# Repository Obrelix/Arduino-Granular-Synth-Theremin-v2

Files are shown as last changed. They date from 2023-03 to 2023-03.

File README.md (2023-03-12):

# Arduino-Granular-Synth-Theremin-v2
An Arduino based projects that utilizes an Arduino Mega 2560 board, 5 10k ohms potentiometers, and 2 IR proximity sensors as inputs.
Based on Peter Knight's Arduino Granular Synth project.

You can explore a vast range of sound textures and manipulate them in real-time. This project is ideal for anyone interested in exploring the boundaries of sound synthesis, especially musicians, sound designers, and electronic hobbyists. With its intuitive interface and customizable controls, its provides an accessible way to experiment with sound and create unique compositions. Whether you're a seasoned pro or a curious beginner, this granular synthesizer is a great way to push the boundaries of sound synthesis and explore the infinite possibilities of sound.

## Implementing a granular synthesis algorithm on an embedded system with a PWM (pulse width modulation) output for audio.

Granular synthesis involves dividing an audio sample into small, overlapping pieces called grains, and then manipulating those grains in various ways (such as changing their pitch, duration, or amplitude) to create new sounds. 

In this project, each grain oscillator generates a triangular waveform with an exponential decay envelope, and the two oscillators are summed together to create the final output sample.

The phase accumulator is a variable that keeps track of the current phase of the oscillator, and is incremented on each audio sample interval. 

The sync phase increment is the amount by which the phase accumulator is incremented each sample interval, and determines the frequency of the oscillator.

The lookup table is used to convert the phase of the oscillator into a triangular waveform. 

The triangle wave is used to modulate the amplitude of the oscillator, which creates the characteristic shape of the exponential decay envelope.

The clipping step ensures that the output sample remains within the range of values that can be represented by the PWM output. Clipping can introduce distortion into the sound, but is often used in audio processing to prevent overdriving the output.

## Bill of Materials
[Arduino Mega 2560 R3](https://www.aliexpress.com/item/1005001621770748.html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) x 1

[IR Proximity Sensor (GP2Y0A41SK0f)](https://www.aliexpress.com/item/1005003745155535.html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) x 2

[Linear Potentiometer 10Κ Ω](https://www.aliexpress.com/item/1005003390403815.html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) x 5

[Toggle Switch (On-Off-On)](https://www.aliexpress.com/item/1005002378931076.html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) x 1

[Momentary Push Button](https://www.aliexpress.com/item/4000164264475.html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) x 1

[LED 5mm](https://www.aliexpress.com/item/32731407139.html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) x 3

[Round Rocker Switch 3Pin red light](https://www.aliexpress.com/item/4000896270246.html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) x 1

[DC Power Jack 5.5 x 2.1 mm](https://www.aliexpress.com/item/33024078085.html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) x 1

[2 Pole Mono 3.5mm audio jack](https://www.aliexpress.com/item/4000169463441.html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) x 1
## Video	
 Watch the video (https://youtu.be/2OcyxWDMjQo)
## Images	
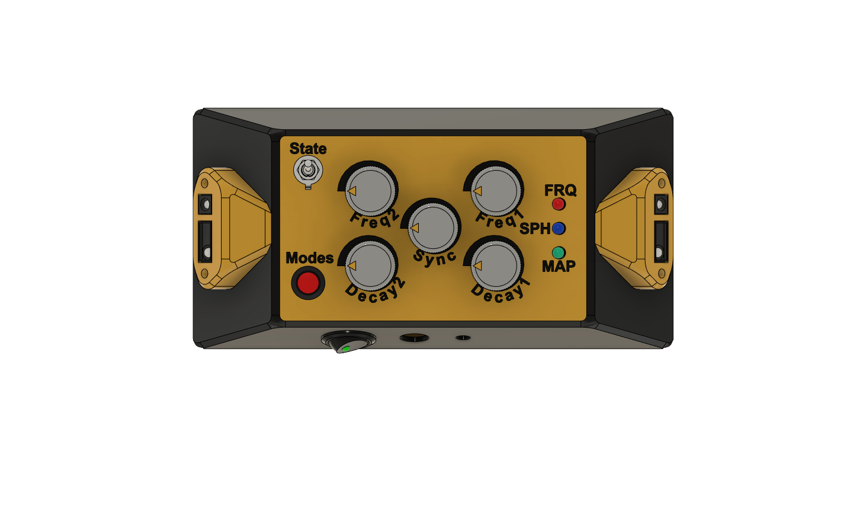
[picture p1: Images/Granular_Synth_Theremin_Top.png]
 
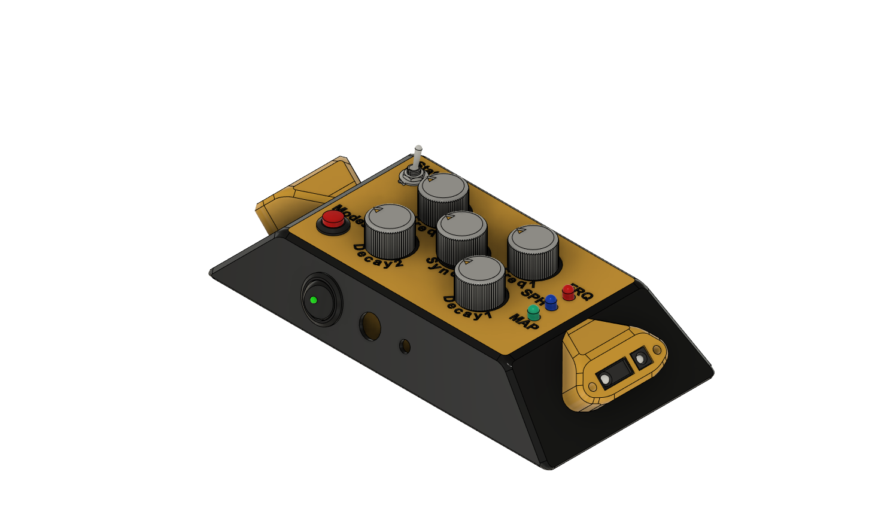
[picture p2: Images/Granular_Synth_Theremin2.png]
 
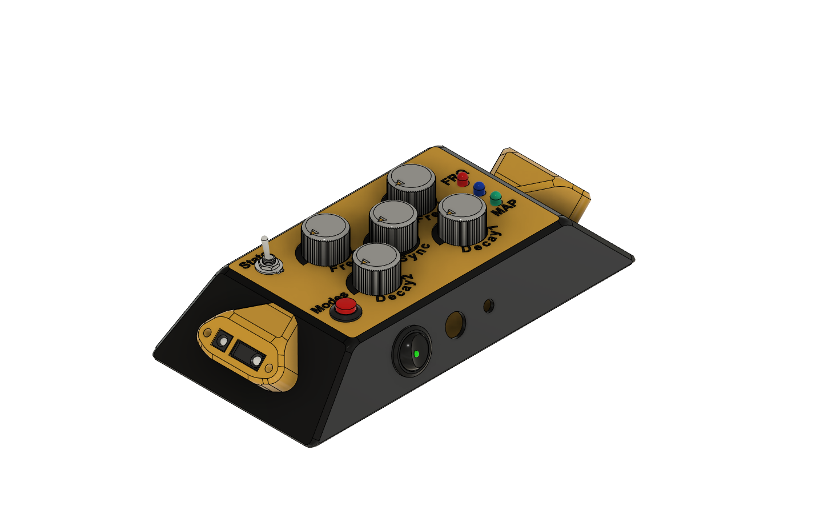
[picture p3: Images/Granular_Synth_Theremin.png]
 
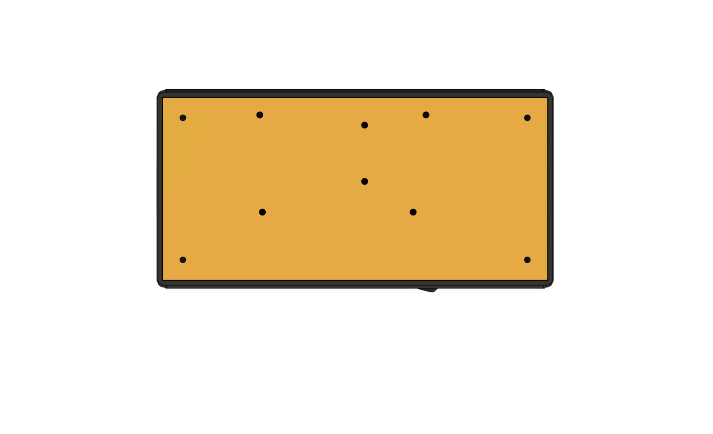
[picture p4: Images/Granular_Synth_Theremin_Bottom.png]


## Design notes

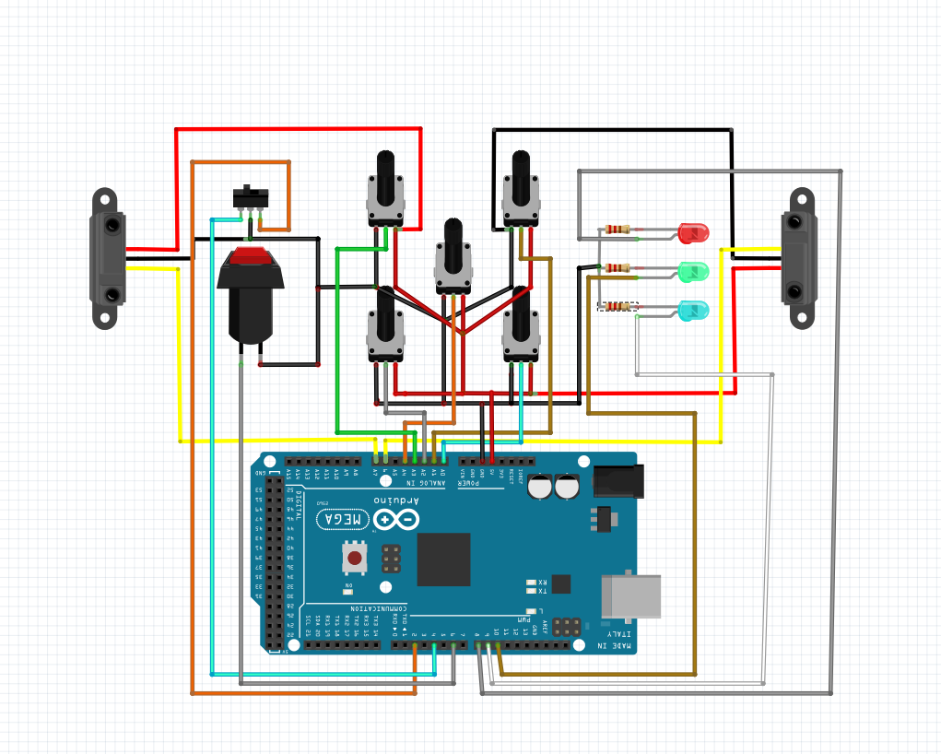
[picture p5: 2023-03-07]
Images/FritzingSchema.PNG

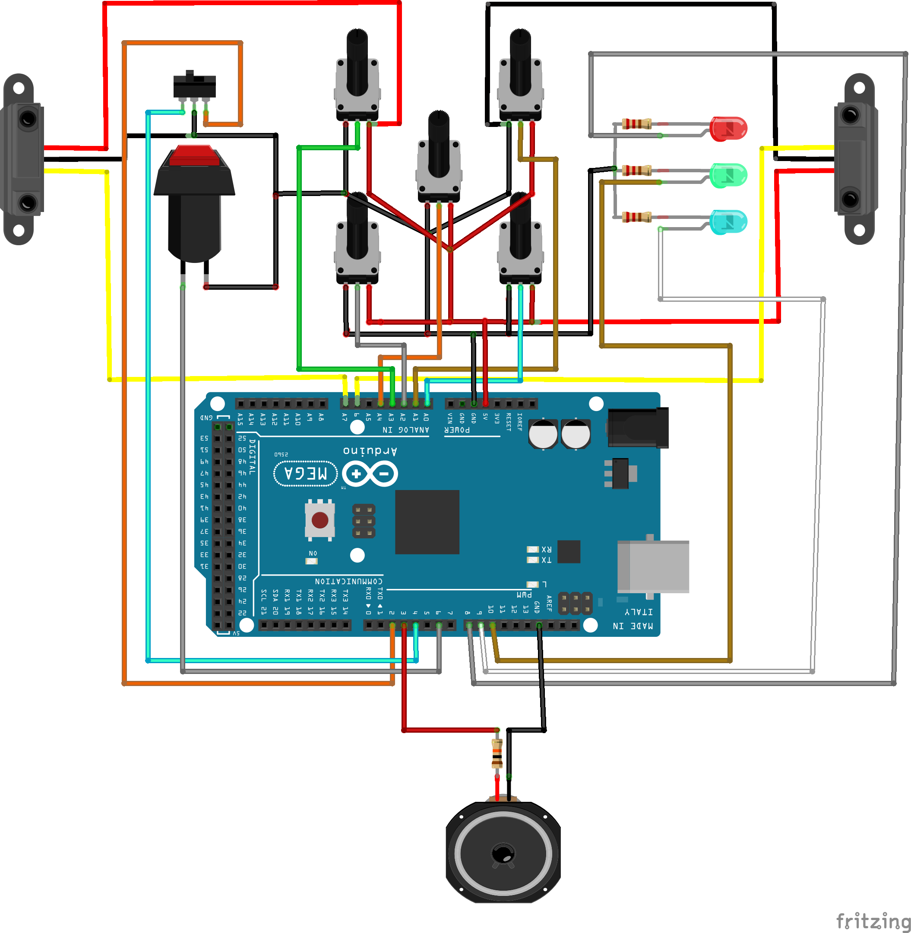
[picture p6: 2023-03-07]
Images/Arduino_Granular_Synth_Theremin_bb.png

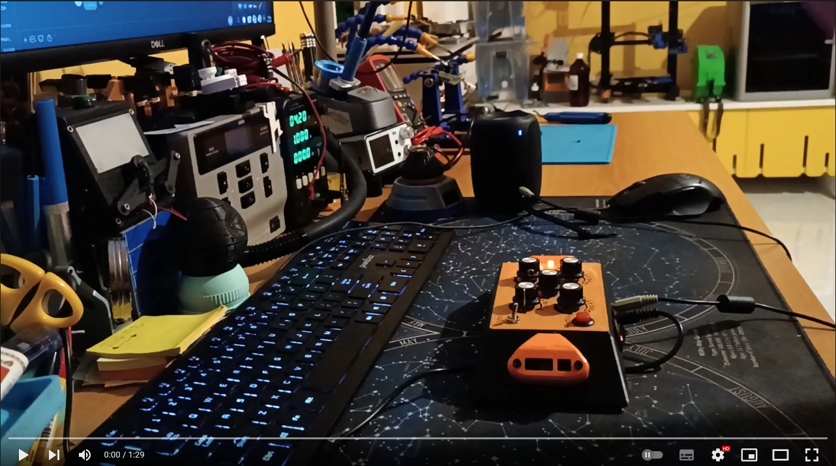
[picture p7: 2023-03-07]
Images/Video Capture.PNG

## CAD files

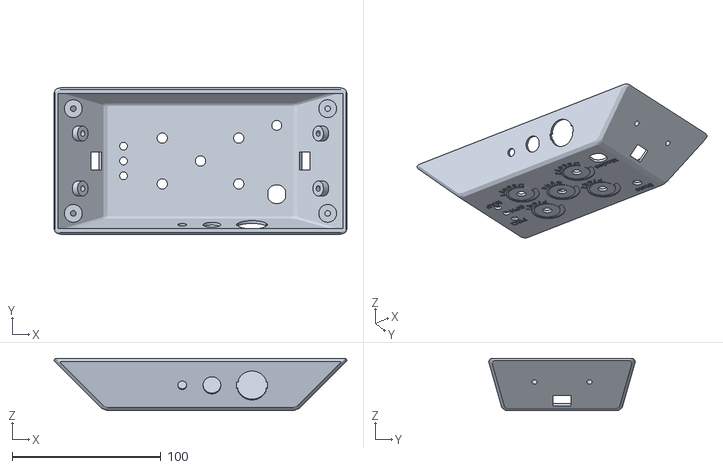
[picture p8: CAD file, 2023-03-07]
STL Files/Main Box.stl
197.2 x 98.9 x 35.0

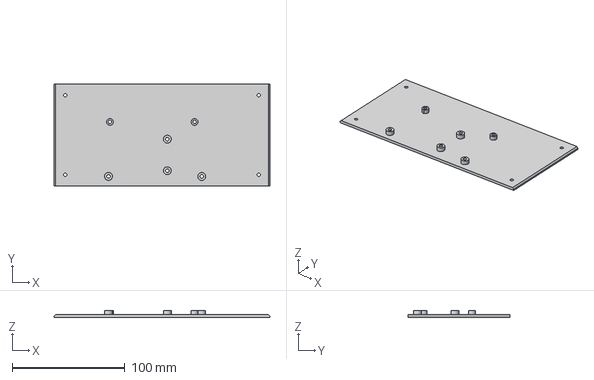
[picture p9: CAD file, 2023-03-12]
Step Files/Bottom-Lid.step
191.2 x 90.5 x 6.25 mm

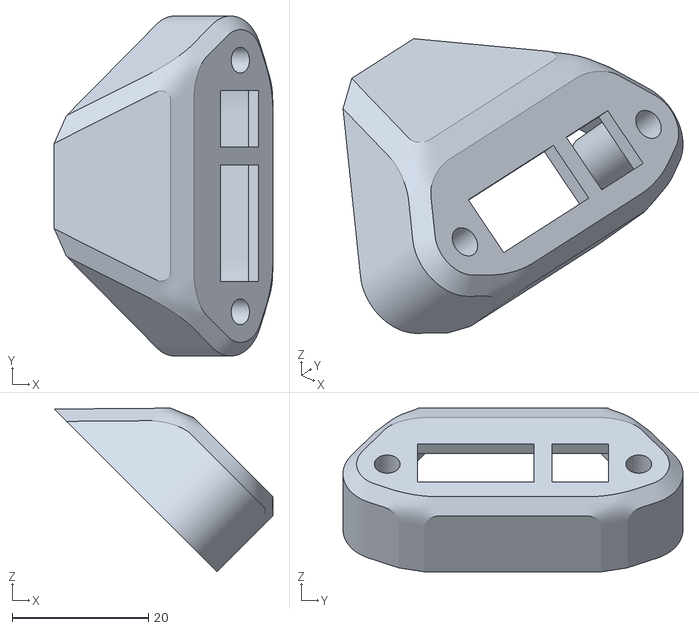
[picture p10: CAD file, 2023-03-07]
STL Files/Distance Sensor Cap.stl
32.2 x 50.0 x 24.1

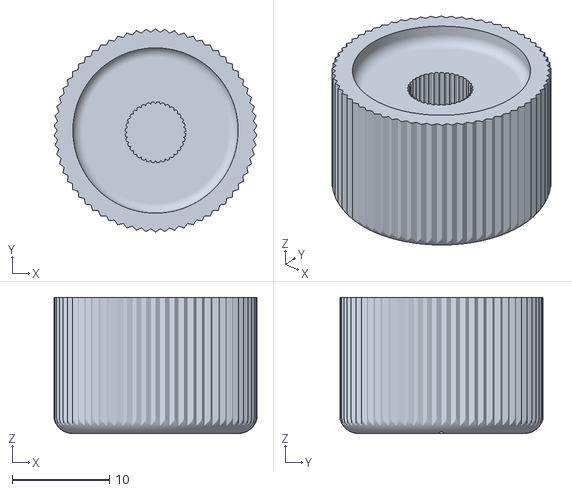
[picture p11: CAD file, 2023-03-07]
STL Files/Knob.stl
20.9 x 20.9 x 14.0

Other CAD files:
Step Files/Proximity-Sensor-Cap.step
STL Files/Bottom-Lid.stl

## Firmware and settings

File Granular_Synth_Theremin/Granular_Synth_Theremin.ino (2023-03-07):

// Based on Peter Knight's Arduino Granular Synth project 
// https://github.com/ndonegan/auduino/blob/master/auduino.pde
#include <avr/io.h>
#include <avr/interrupt.h>
// Define Analogue Inputs
#define SYNC_CONTROL         (4) // Sync pot pin
#define GRAIN_FREQ_CONTROL   (1) // Freq1 pot pin
#define GRAIN_DECAY_CONTROL  (0) // Decay1 pot pin
#define GRAIN2_FREQ_CONTROL  (3) // Freq2 pot pin
#define GRAIN2_DECAY_CONTROL (2) // Decay2 pot
#define LEFT_PROX_SENSOR     (6) // Left proximity sensor pin 
#define RIGHT_PROX_SENSOR    (7) // Right proximity sensor pin 
//Define Digital IOs
#define TOGGLE_DOWN_PIN      (2) // toggle switch down pin 
#define TOGGLE_UP_PIN        (4) // toggle switch up pin 
#define MODE_BTN_PIN         (6) // push button pin 
#define SPH_LED_PIN          (10)// SPH LED pin 
#define FRQ_LED_PIN          (8) // FRQ LED pin 
#define MAP_LED_PIN          (9) // MAP LED pin  
// Define audio values for Arduino Mega
#define LED_PIN       13
#define LED_PORT      PORTB
#define LED_BIT       7
#define PWM_PIN       3 
#define PWM_VALUE     OCR3C
#define PWM_INTERRUPT TIMER3_OVF_vect

uint16_t syncPhaseAcc;
uint16_t syncPhaseInc;
uint16_t grainPhaseAcc;
uint16_t grainPhaseInc;
uint16_t grainAmp;
uint8_t grainDecay;
uint16_t grain2PhaseAcc;
uint16_t grain2PhaseInc;
uint16_t grain2Amp;
uint8_t grain2Decay;
volatile uint16_t mapLEDState = LOW;   
long previousMillis = 0;       
uint16_t BlinkRate = 5;           
uint16_t mapLEDBlinkCount = 0;          
uint16_t mapLEDBlinkLoopLength = 14;    
uint16_t syncValue = 0;
uint16_t freq1Value = 0;
uint16_t freq2Value = 0;
uint16_t toggleDownValue = 0;
uint16_t toggleUpValue = 0;
uint16_t btnModeValue;          
uint16_t buttonState;         
uint16_t leftPSValue = 0;     
uint16_t rightPSValue = 0;    
uint16_t psMin = 40;           // minimum proximity sensor value
uint16_t psMax = 620;         // maximum proximity sensor value
uint16_t mapMode = 0;        
//Mode 0:Smooth Logarithmic mapping
//Mode 1:Chromatic mapping
//Mode 2:Major Diatonic mapping
//Mode 3:Minor Diatonic mapping
//Mode 4:Pentatonic mapping
//Mode 5:Major Pentatonic mapping
//Mode 6:Minor Pentatonic mapping

void setup() {
  pinMode(SPH_LED_PIN, OUTPUT);
  pinMode(FRQ_LED_PIN, OUTPUT);   
  pinMode(MAP_LED_PIN, OUTPUT);
  digitalWrite(SPH_LED_PIN, HIGH);
  digitalWrite(FRQ_LED_PIN, HIGH);
  digitalWrite(MAP_LED_PIN, HIGH);
  pinMode(PWM_PIN, OUTPUT);
  audioOn();
  pinMode(TOGGLE_DOWN_PIN, INPUT_PULLUP);
  pinMode(TOGGLE_UP_PIN, INPUT_PULLUP);
  pinMode(MODE_BTN_PIN, INPUT_PULLUP);
  digitalWrite(SPH_LED_PIN, LOW);
  digitalWrite(FRQ_LED_PIN, LOW);
  digitalWrite(MAP_LED_PIN, LOW);
}

void loop() {
  toggleDownValue = digitalRead(TOGGLE_DOWN_PIN); 
  toggleUpValue   = digitalRead(TOGGLE_UP_PIN); 
  btnModeValue    = digitalRead(MODE_BTN_PIN); 
  if (btnModeValue != buttonState) { 
    if(btnModeValue == 0){
      mapMode++; 
      if(mapMode > 6) 
        mapMode = 0; 
    }
    buttonState = btnModeValue;   
  }
  if (millis() - previousMillis > 1000/BlinkRate){
    mapLEDBlinkCount ++;
    previousMillis = millis();
    digitalWrite(MAP_LED_PIN, LOW);
    if (mapLEDBlinkCount <= (mapMode+1)*2) {
      mapLEDState = !mapLEDState;
      digitalWrite(MAP_LED_PIN, mapLEDState);
    } else if (mapLEDBlinkCount >= mapLEDBlinkLoopLength) {
      mapLEDBlinkCount = 0;   
    }
  }
  if(toggleDownValue == 0){
    leftPSValue  = analogRead(LEFT_PROX_SENSOR);
    rightPSValue = analogRead(RIGHT_PROX_SENSOR);
    freq2Value   = analogRead(GRAIN2_FREQ_CONTROL);
    analogWrite(SPH_LED_PIN, (leftPSValue+rightPSValue)/2);
    leftPSValue  = constrain(map(leftPSValue, psMin, psMax, 512, 1023), 512, 1023);
    rightPSValue = constrain(map(rightPSValue, psMin, psMax, 256, 1023), 256, 1023);
    syncValue    = rightPSValue;
    freq1Value   = 1024 - leftPSValue;
  }else if(toggleUpValue == 0){
    leftPSValue  = analogRead(LEFT_PROX_SENSOR);
    rightPSValue = analogRead(RIGHT_PROX_SENSOR);
    syncValue    = analogRead(SYNC_CONTROL);
    analogWrite(SPH_LED_PIN, (leftPSValue+rightPSValue)/2);
    leftPSValue  = constrain(map(leftPSValue, psMin, psMax, 512, 1023), 512, 1023);
    rightPSValue = constrain(map(rightPSValue, psMin, psMax, 512, 1023), 512, 1023);
    freq2Value   = 1024 - leftPSValue;
    freq1Value   = 1024 - rightPSValue;
  }else {
    syncValue    = analogRead(SYNC_CONTROL);
    freq2Value   = analogRead(GRAIN2_FREQ_CONTROL);
    freq1Value   = analogRead(GRAIN_FREQ_CONTROL);
    digitalWrite(SPH_LED_PIN, LOW);
  }
  switch (mapMode) {
    case 0:
      syncPhaseInc = MapPhaseInc(syncValue) / 4;
      break;
    case 1:
      syncPhaseInc = MapMidi(syncValue);
      break;
    case 2:
      syncPhaseInc = MapMajorDiatonic(syncValue);
      break;
    case 3:
      syncPhaseInc = MapMinorDiatonic(syncValue);
      break;
    case 4:
      syncPhaseInc = MapPentatonic(syncValue);
      break;
    case 5:
      syncPhaseInc = MapMajorPentatonic(syncValue);
      break;
    case 6:
      syncPhaseInc = MapMinorPentatonic(syncValue);
      break;
  }
  grainPhaseInc  = MapPhaseInc(freq1Value) / 2;
  grainDecay     = analogRead(GRAIN_DECAY_CONTROL) / 8;
  grain2PhaseInc = MapPhaseInc(freq2Value) / 2;
  grain2Decay    = analogRead(GRAIN2_DECAY_CONTROL) / 4;
  digitalWrite(FRQ_LED_PIN, PWM_VALUE);
}

SIGNAL(PWM_INTERRUPT){
  uint8_t value;
  uint16_t output;

  syncPhaseAcc += syncPhaseInc;
  if (syncPhaseAcc < syncPhaseInc) {
    // Time to start the next grain
    grainPhaseAcc = 0;
    grainAmp = 0x7fff;
    grain2PhaseAcc = 0;
    grain2Amp = 0x7fff;
    LED_PORT ^= 1 << LED_BIT; // Faster than using digitalWrite
  }

  // Increment the phase of the grain oscillators
  grainPhaseAcc += grainPhaseInc;
  grain2PhaseAcc += grain2PhaseInc;

  // Convert phase into a triangle wave
  value = (grainPhaseAcc >> 7) & 0xff;
  if (grainPhaseAcc & 0x8000) value = ~value;
  // Multiply by current grain amplitude to get sample
  output = value * (grainAmp >> 8);

  // Repeat for second grain
  value = (grain2PhaseAcc >> 7) & 0xff;
  if (grain2PhaseAcc & 0x8000) value = ~value;
  output += value * (grain2Amp >> 8);

  // Make the grain amplitudes decay by a factor every sample (exponential decay)
  grainAmp -= (grainAmp >> 8) * grainDecay;
  grain2Amp -= (grain2Amp >> 8) * grain2Decay;

  // Scale output to the available range, clipping if necessary
  output >>= 9;
  if (output > 255) output = 255;

  // Output to PWM (this is faster than using analogWrite)  
  PWM_VALUE = output;
}

void audioOn() {
  //ARDUINO MEGA Compatible
  TCCR3A = _BV(COM3C1) | _BV(WGM30);
  TCCR3B = _BV(CS30);
  TIMSK3 = _BV(TOIE3);
}

// MAPPINGS - START
// Smooth logarithmic mapping
uint16_t antilogTable[] = {
  64830,64132,63441,62757,62081,61413,60751,60097,59449,58809,58176,57549,56929,56316,55709,55109,
  54515,53928,53347,52773,52204,51642,51085,50535,49991,49452,48920,48393,47871,47356,46846,46341,
  45842,45348,44859,44376,43898,43425,42958,42495,42037,41584,41136,40693,40255,39821,39392,38968,
  38548,38133,37722,37316,36914,36516,36123,35734,35349,34968,34591,34219,33850,33486,33125,32768
};
uint16_t MapPhaseInc(uint16_t input) {
  return (antilogTable[input & 0x3f]) >> (input >> 6);
}

// Stepped chromatic mapping
uint16_t midiTable[] = {
  0,17,18,19,20,22,23,24,26,27,29,31,32,34,36,38,41,43,46,48,51,54,58,61,65,69,73,
  77,82,86,92,97,103,109,115,122,129,137,145,154,163,173,183,194,206,218,231,
  244,259,274,291,308,326,346,366,388,411,435,461,489,518,549,581,616,652,691,
  732,776,822,871,923,978,1036,1097,1163,1232,1305,1383,1465,1552,1644,1742,
  1845,1955,2071,2195,2325,2463,2610,2765,2930,3104,3288,3484,3691,3910,4143,
  4389,4650,4927,5220,5530,5859,6207,6577,6968,7382,7821,8286,8779,9301,9854,
  10440,11060,11718,12415,13153,13935,14764,15642,16572,17557,18601,19708,20879,
  22121,23436,24830,26306,27871
};
uint16_t MapMidi(uint16_t input) {
  return (midiTable[(1023-input) >> 3]);
}

// Stepped Pentatonic mapping
uint16_t pentatonicTable[54] = {
  0,19,22,26,29,32,38,43,51,58,65,77,86,103,115,129,154,173,206,231,259,308,346,
  411,461,518,616,691,822,923,1036,1232,1383,1644,1845,2071,2463,2765,3288,
  3691,4143,4927,5530,6577,7382,8286,9854,11060,13153,14764,16572,19708,22121,26306
};
uint16_t MapPentatonic(uint16_t input) {
  uint8_t value = (1023-input) / (1024/53);
  return (pentatonicTable[value]);
}

// Stepped major Diatonic mapping
uint16_t majorDiatonicTable[76] = {
  0,17,19,22,23,26,29,32,34,38,43,46,51,58,65,69,77,86,92,103,115,129,137,154,173,183,206,231,259,274,308,346,366,
  411,461,518,549,616,691,732,822,923,1036,1097,1232,1383,1465,1644,1845,2071,2195,2463,2765,2930,3288,
  3691,4143,4389,4927,5530,5859,6577,7382,8286,8779,9854,11060,11718,13153,14764,16572,17557,19708,22121,23436,26306
};
uint16_t MapMajorDiatonic(uint16_t input) {
  uint8_t value = (1023-input) / (1024/53);
  return (majorDiatonicTable[value]);
}

// Stepped minor Diatonic mapping
uint16_t minorDiatonicTable[76] = {
  0,17,19,20,23,26,27,31,34,38,41,46,51,54,61,69,77,82,92,103,109,122,137,154,163,183,206,218,244,274,308,326,366,
  411,435,489,549,616,652,732,822,871,978,1097,1232,1305,1465,1644,1742,1955,2195,2463,2610,2930,3288,
  3484,3910,4389,4927,5220,5859,6577,6968,7821,8779,9854,10440,11718,13153,13935,15642,17557,19708,20879,23436,26306
};
uint16_t MapMinorDiatonic(uint16_t input) {
  uint8_t value = (1023-input) / (1024/53);
  return (minorDiatonicTable[value]);
}

// Stepped major Pentatonic mapping
uint16_t majorPentatonicTable[55] = {
  0,17,19,22,26,29,34,38,43,51,58,69,77,86,103,115,137,154,173,206,231,274,308,346,
  411,461,549,616,691,822,923,1097,1232,1383,1644,1845,2195,2463,2765,3288,
  3691,4389,4927,5530,6577,7382,8779,9854,11060,13153,14764,17557,19708,22121,26306
};
uint16_t MapMajorPentatonic(uint16_t input) {
  uint8_t value = (1023-input) / (1024/53);
  return (majorPentatonicTable[value]);
}

// Stepped minor Pentatonic mapping
uint16_t minorPentatonicTable[55] = {
  0,17,20,23,26,31,34,41,46,51,61,69,82,92,103,122,137,163,183,206,244,274,326,366,
  411,489,549,652,732,822,978,1097,1305,1465,1644,1955,2195,2610,2930,3288,
  3910,4389,5220,5859,6577,7821,8779,10440,11718,13153,15642,17557,20879,23436,26306
};
uint16_t MapMinorPentatonic(uint16_t input) {
  uint8_t value = (1023-input) / (1024/53);
  return (minorPentatonicTable[value]);
}
// MAPPINGS - END

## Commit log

2023-03-07 Create Granular_Synth_Theremin.ino
    Arduino Code Added
2023-03-07 Create Arduino_Granular_Synth_Theremin.fzz
    Fritzing Schema Added
    [Arduino_Granular_Synth_Theremin.fzz]
2023-03-07 STL Files Added
    [Bottom-Lid.stl, Distance Sensor Cap.stl, Knob.stl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]
2023-03-07 Fitzing updated
    [Arduino_Granular_Synth_Theremin.fzz]
2023-03-07 Images uploaded
    [Arduino_Granular_Synth_Theremin.fzz]
2023-03-12 Step Files Added
    [Bottom-Lid.step, Proximity-Sensor-Cap.step]
